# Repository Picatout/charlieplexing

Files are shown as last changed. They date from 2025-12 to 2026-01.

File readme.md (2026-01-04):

# CharliePlexing demonstration

Using a STM8L001J3 MCU  12 LEDs are multiplexed on 4 I/O

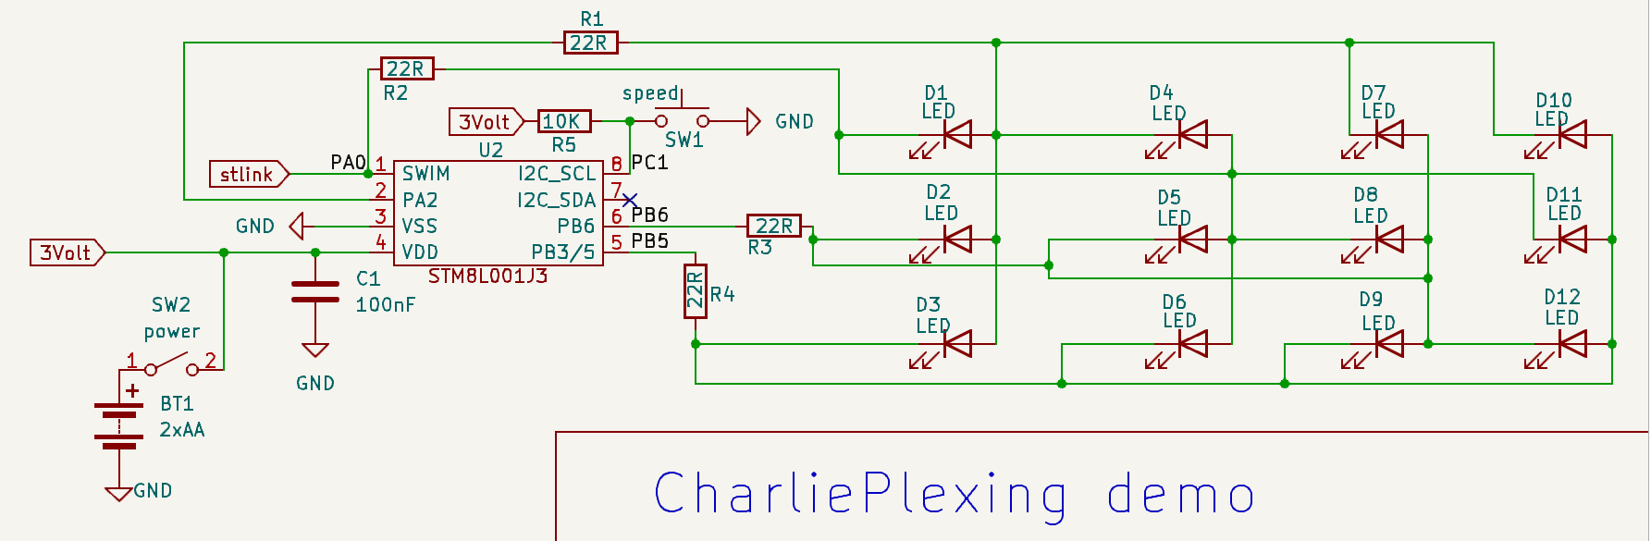
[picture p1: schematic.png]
schematic


## notes 

1.  Le bouton lorsqu'enfoncé accéllère le multiplexage à environ 83 cycles par seconde pour un scan complet des 12 LEDs. Ce qui donne l'impression qu'elles sont toutes allumées en même temps à cause du phénomène appellé persistance de la vsion.
1.  Les LEDs peuvent être de la couleur de votre choix. Avec un alimentation de 3 volts même les LEDs bleus ou blanches émettent de la lumière.
1. Si des LEDs bleus ou blanches sont utilisées les résistances **R1** à **R4** peuvent être retirées du circuit. Ces LEDs opèrent habituellement à 3.2 volts mais à 3 volts elles consomme environ 15mA ce qui est dans les limites pour les spécifications des E/S  du MCU STM8L001J3 et produit amplement de luminosité.

## Version 2

J'ai construit une version permanente du circuit en faisant quelques modifications. D'abord cette version utilise des DELs bleus et les résistances **R1** à **R4** ont étées remplacées par des 15 ohms. 

Sur les broches 7 et 8 du MCU j'ai ajouter 2 boutons pour sélectionner l'animation active du programme [animation-demo.asm](animation-demo.asm).

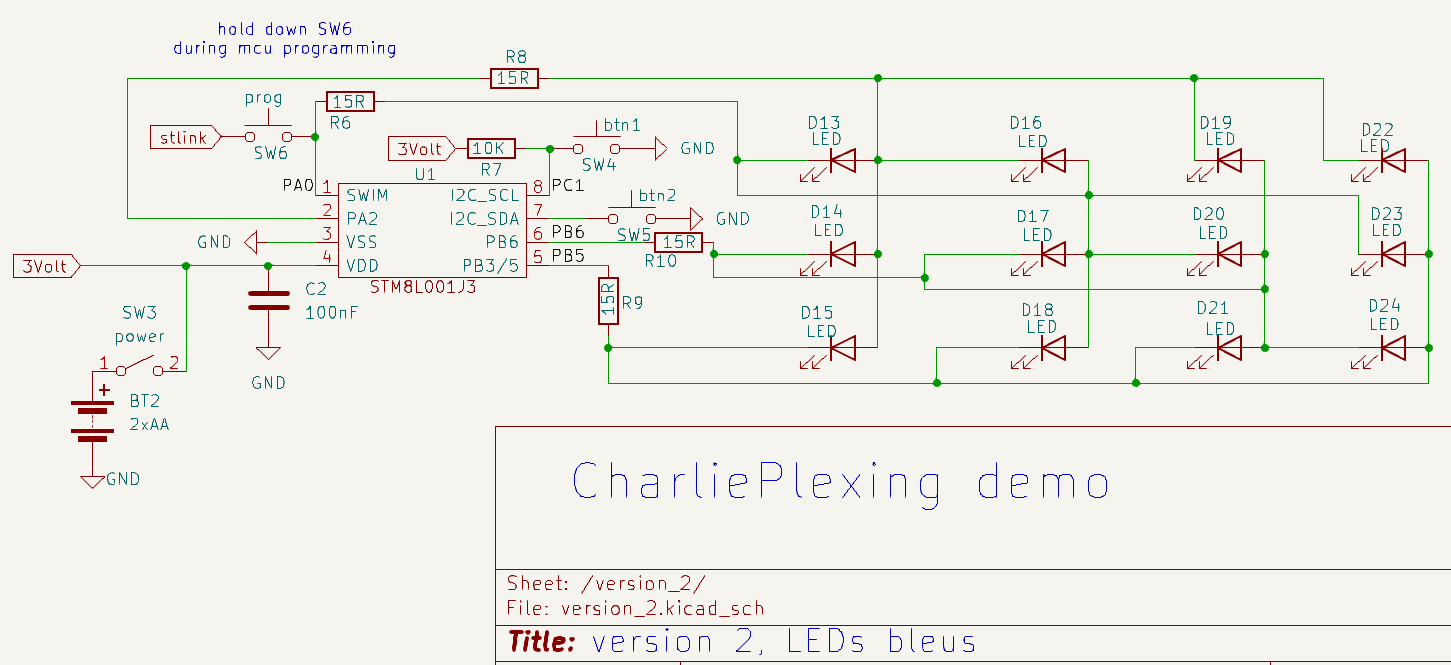
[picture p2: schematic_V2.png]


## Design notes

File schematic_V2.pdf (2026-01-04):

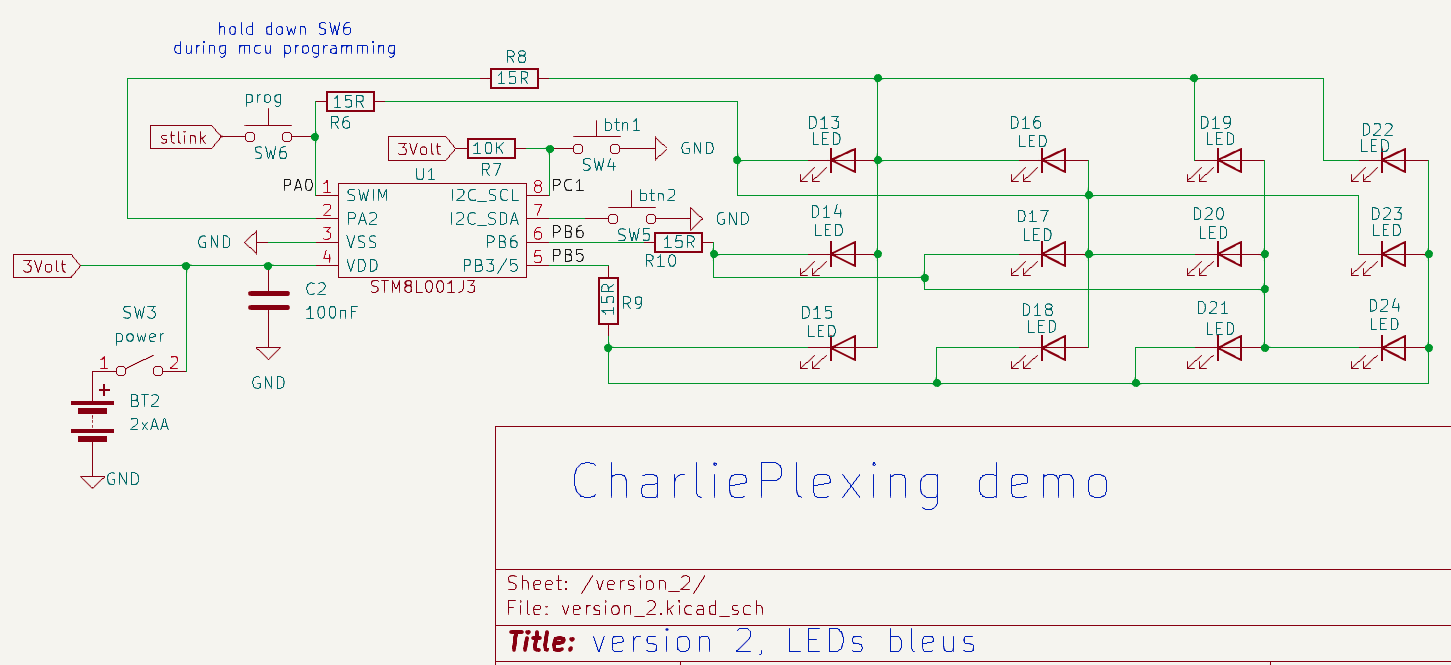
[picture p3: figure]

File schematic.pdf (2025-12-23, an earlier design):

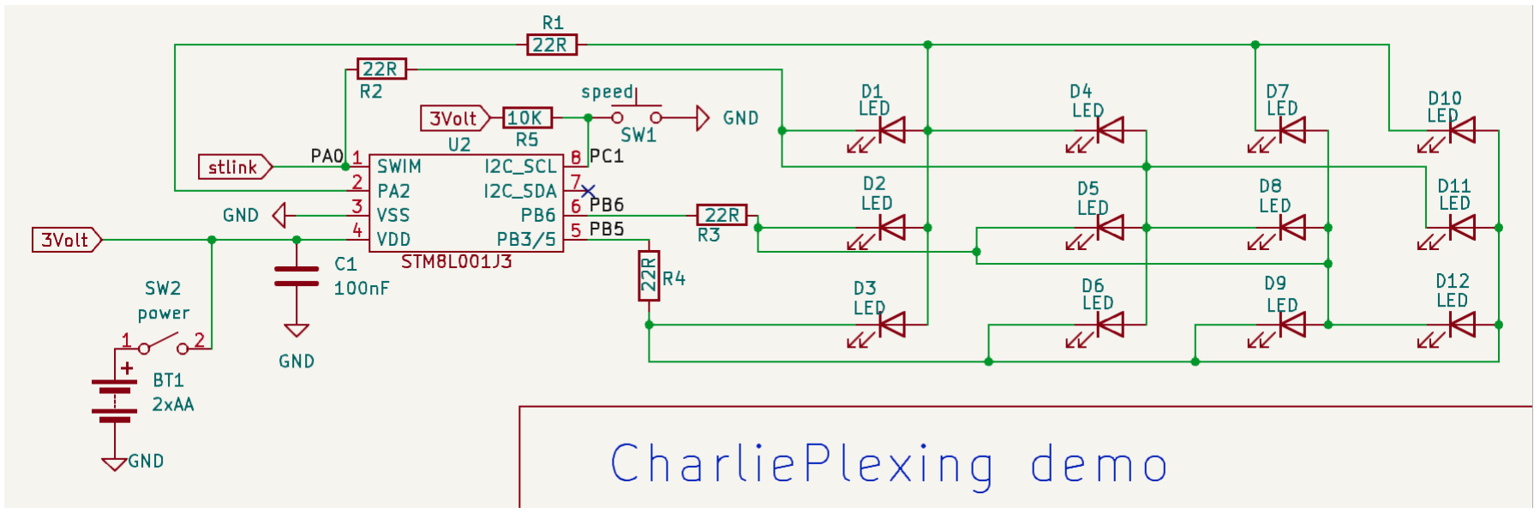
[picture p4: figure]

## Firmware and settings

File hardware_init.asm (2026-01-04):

;;
; Copyright Jacques Deschênes 2025,2026  
; This file is part of CharliePlexing-demo.asm  
;
;     CharliePlexing-demo.asm is free software: you can redistribute it and/or modify
;     it under the terms of the GNU General Public License as published by
;     the Free Software Foundation, either version 3 of the License, or
;     (at your option) any later version.
;
;     CharliePlexing-demo.asm is distributed in the hope that it will be useful,
;     but WITHOUT ANY WARRANTY; without even the implied warranty of
;     MERCHANTABILITY or FITNESS FOR A PARTICULAR PURPOSE.  See the
;     GNU General Public License for more details.
;
;     You should have received a copy of the GNU General Public License
;     along with CharliePlexing-demo.asm.  If not, see <http://www.gnu.org/licenses/>.
;;

;;;;;;;;;;;;;;;;;;;;;;;;;;;;;;;
;;; hardware initialisation
;;;;;;;;;;;;;;;;;;;;;;;;;;;;;; 

    .module HW_INIT 


STACK_SIZE=128
STACK_EMPTY=RAM_SIZE-1 
DISPLAY_BUFFER_SIZE=128 ; horz pixels   

;;-----------------------------------
    .area SSEG (ABS)
;; working buffers and stack at end of RAM. 	
;;-----------------------------------
    .org RAM_END - STACK_SIZE - 1
free_ram_end: 
stack_full: .ds STACK_SIZE   ; control stack 
stack_unf: ; stack underflow ; control_stack bottom 


;--------------------------------------
    .area DATA (ABS)
	.org 2 
;--------------------------------------	

mx_step: .blkb 1 ; multiplexer step 
led_set: .blkw 1 ; bits pattern for LEDs control 
anim_delay: .blkb 1 ; animation speed delay, multiple of 12 msec 
pause_timer: .blkb 1 ; pause cowntdown timer, mulitple of 12 msec  
anim_select: .blkb 1 ; selected animation 
anim_step: .blkb 1 ; animation table step  
anim_table:  .blkw 1 ; animation table address
flags: .blkb 1 ; various boolean flags
seed: .blkw 1  ; prng seed  used by lfsr() function 
debounce: .blkb 1; switches debounce counter 
switches_state: .blkb 1 ; last switches state 

	.org 0x100

free_ram: ; from here RAM free up to free_ram_end 


	.area CODE 

;;;;;;;;;;;;;;;;;;;;;;;;;;;;
; non handled interrupt 
; reset MCU
;;;;;;;;;;;;;;;;;;;;;;;;;;;
NonHandledInterrupt:
	iret 

;------------------------------
; TIMER 4 is used to maintain 
; timers and ticks 
; interrupt interval is 1 msec 
;--------------------------------
Timer4UpdateHandler:
	clr TIM4_SR ; reset interrupt flag 
; multiplexer control 	
	call leds_off 
	ld a,mx_step 
	inc a
	cp a,#12
	jrmi 1$ 
	clr a
4$:
; check if pause is active 	
	btjf flags,#F_PAUSE,1$
	dec pause_timer
	jrne 1$ 
; end of pause
	bres flags, #F_PAUSE 
1$: 
; turn on LED if bit set 
; shift the corresponding bit in carry 
    ld mx_step, a 
	ldw x, led_set
	tnz a 
	jreq 3$ 
2$:	srlw x 
	dec a 
	jrne 2$
3$: srLw x ; now bit is in carry flag 
	jrnc 9$ ; bit is reset 
; bit set turn on LED 	
	ld a,mx_step 
	call led_on 
9$: callr read_buttons
	iret 


;;;;;;;;;;;;;;;;;;;;;;;;;;;;;;;;;;;;;;;;;
;    peripherals initialization
;;;;;;;;;;;;;;;;;;;;;;;;;;;;;;;;;;;;;;;;;

;----------------------------------------
; inialize MCU clock 
; HSI no divisor 
; FMSTR=16Mhz 
;----------------------------------------
clock_init:	
	clr CLK_CKDIVR ; pas de division Fmstr=16Mhz 
	ret

;---------------------------------
; TIM4 is configured to generate an 
; interrupt every 1.66 millisecond 
;----------------------------------
timer4_init:
	bset CLK_PCKENR1,#CLK_PCKENR1_TIM4
	bres TIM4_CR1,#TIM4_CR1_CEN 
	mov TIM4_PSCR,#7 ; Fmstr/128=125000 hertz  
	mov TIM4_ARR,#(256-125) ; 125000/125=1 msec 
	mov TIM4_CR1,#((1<<TIM4_CR1_CEN)|(1<<TIM4_CR1_URS))
	bset TIM4_IER,#TIM4_IER_UIE
	ret

;-------------------------
; read btn1 and btn2 
; switches 
;-------------------------
read_buttons:
    ld a,PC+GPIO_IDR 
    and a,#(1<<BTN1_BIT)|(1<<BTN2_BIT)
	xor a,#(1<<BTN1_BIT)|(1<<BTN2_BIT)
	
	cp  a,switches_state 
    jrne 8$
    inc debounce
    ld a,#20
    cp a,debounce 
    jrpl 9$ 
	bres flags,#F_BTN1 
	bres flags,#F_BTN2 
	ld a,switches_state 
	or a,flags 
    ld flags,a 
    jra 9$ 
8$: clr debounce 
	ld switches_state,a
9$:    
    ret 

;-------------------------
; pseudo random number 
; generator using 
; Galois Linear Feedback 
; shift Register. 
;------------------------
MASK=0XB4
lfsr:
	ldw x,seed 
	srlw x
	ldw seed,x 
	jrnc 9$ 
	ld a, seed 
	xor a,#MASK
	ld seed,a 
9$:
	ret 

;-----------------------------------
; suspend execution 
; input:
;   a  pause in multiple of 12 msec  
;-----------------------------------
pause:
	ld pause_timer,a  
	bset flags,#F_PAUSE  
1$: wfi 	
	btjt flags,#F_PAUSE,1$ 
	ret
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

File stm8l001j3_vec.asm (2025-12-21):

;---------------------------------------
;  STM8L001J3  vectors table 
;---------------------------------------

;;--------------------------------------
;; interrupt vector table at 0x8000
;;--------------------------------------
    .area HOME 

	int cold_start	        ; reset
	int NonHandledInterrupt	; trap
	int 0               	; irq0 not used 
	int NonHandledInterrupt	; irq1 FLASH  
	int 0               	; irq2 DMA1 0/1
	int 0               	; irq3 DMA1 2/3
	int NonHandledInterrupt	; irq4 AWU 
	int 0               	; irq5 PVD  
	int NonHandledInterrupt	; irq6 EXTIB
	int NonHandledInterrupt	; irq7 EXTID 
	int NonHandledInterrupt	; irq8 EXTI0  
	int NonHandledInterrupt	; irq9 EXTI1 
	int NonHandledInterrupt	; irq10 EXTI2  
	int NonHandledInterrupt	; irq11 EXTI3  
	int NonHandledInterrupt	; irq12 EXTI4  
	int NonHandledInterrupt	; irq13 EXTI5 
	int NonHandledInterrupt	; irq14 EXTI6  
	int NonHandledInterrupt	; irq15 EXTI7  
	int 0               	; irq16 reserved 
	int 0               	; irq17 reserved 
	int NonHandledInterrupt	; irq18 COMP   
	int NonHandledInterrupt	; irq19 TIM2 OVF  
	int NonHandledInterrupt	; irq20 TIM2 CAP/COMP 
    int NonHandledInterrupt	; irq21 TIM3 OVF 
	int NonHandledInterrupt	; irq22 TIM3 CAP/COMP
	int 0                   ; irq23 reserved 
	int 0               	; irq24 reserved  
	int Timer4UpdateHandler	; irq25 TIM4 OVF 
	int NonHandledInterrupt	; irq26 SPI1 
	int NonHandledInterrupt	; irq27 USART TX 
	int NonHandledInterrupt	; irq28 USART1 RX 
	int NonHandledInterrupt	; irq29 I2C1 
 

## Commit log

2025-12-21 Premier commit du projet CharliePlexing demo
    [charliePlexing.kicad_pcb, charliePlexing.kicad_sch]
2025-12-21 First build
    [charliePlexing.kicad_sch]
2025-12-21 premier test du démo
    [charliePlexing.kicad_sch]
2025-12-22 premier test avec 12 LEDs
2025-12-23 modification de l'application pour utiliser le TIMER 4 pour générer un délais de 1 msec.
2025-12-23 Ajout de la switch contrôlant la vitesse du scan
    [charliePlexing.kicad_sch]
2025-12-30 travail sur version 2
    [charliePlexing.kicad_sch]
2026-01-01 Ajout du bit d'inversion et ajout de l'animation butterfly
2026-01-01 ajout de l'animation fill
2026-01-04 version 2.2, ajout de l'animation swing
2026-01-04 ajout de fichiers
2026-01-04 Ajout de fichiers au git
2026-01-05 modification mineure
    [charliePlexing.kicad_sch]
